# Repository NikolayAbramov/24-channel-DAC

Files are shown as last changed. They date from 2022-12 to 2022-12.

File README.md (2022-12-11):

# 24-channel DAC
This is hardware project of a 24-channel DAC with isolated output controlled via Ethernet interface. 

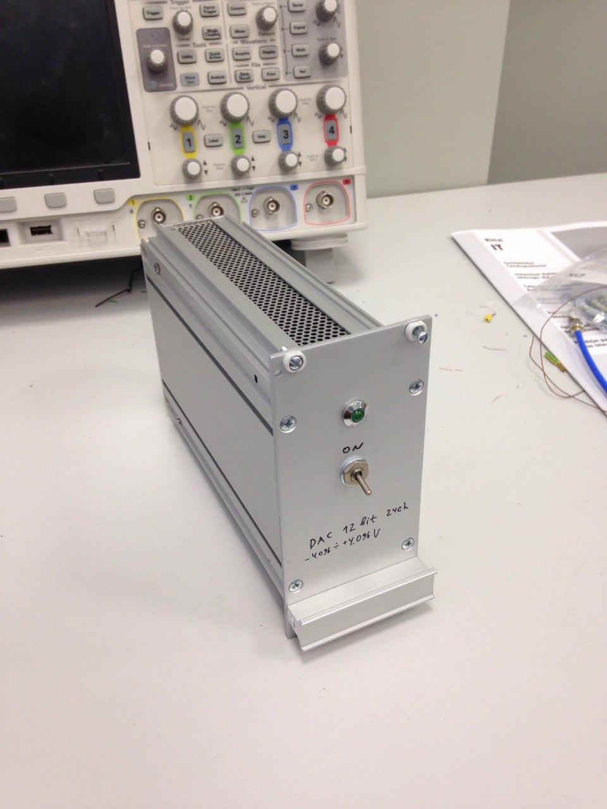
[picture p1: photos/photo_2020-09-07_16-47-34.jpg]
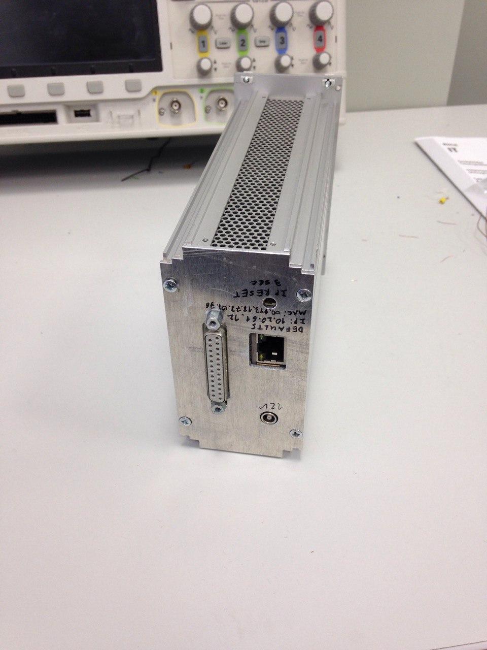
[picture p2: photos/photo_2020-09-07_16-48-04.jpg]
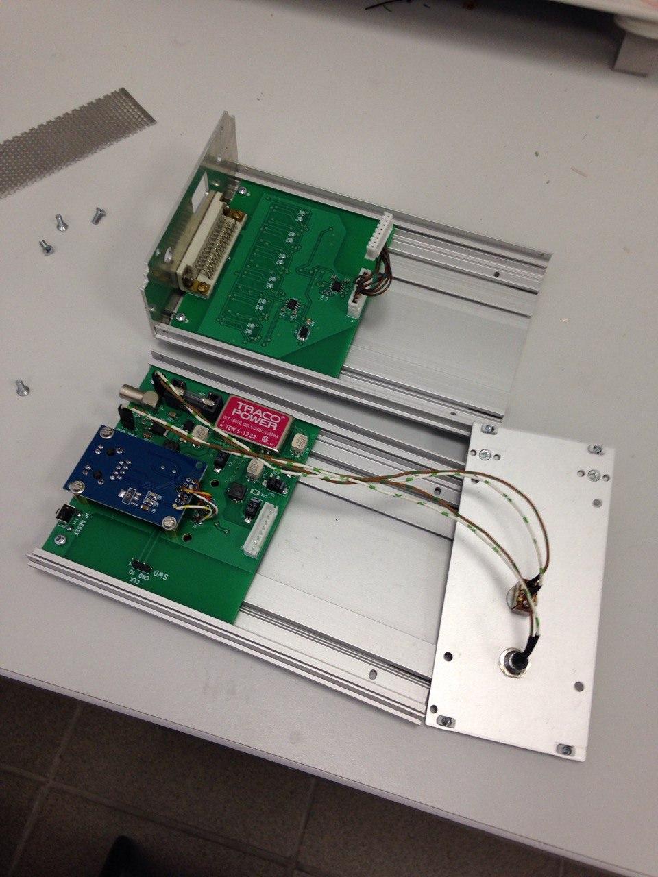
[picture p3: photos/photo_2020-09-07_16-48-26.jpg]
  

# Specs
- Number of outputs: 24
- Resolution: 10 bit
- Output voltage: from -4.096 V to +4.096 V
- Output current: 10 mA max
- Output configuration: 24 channels with common rail, isolated from power supply
- Control: Ethernet with web interface and SCPI commands
- Power: 12V

# Details
The schematics and PCB files can be found in the /kicad folder, they are created using KiCAD. The schematics are also presented in PDF. There are 2 boards: the controller bord and the DAC board. The controller board contains a STM32 MCU, an isolated power coverter and an Ethernet PHY module. An of-the-shelf ENC28J60 module is used for the Ethernet. The DAC board is connected via isolated I2C and contains four 8-channel DAC ICs, reference source and output buffers.

The firmware for STM32 MCU can be found in the /STM32_firmware folder. The project is for STM32CubeIDE.

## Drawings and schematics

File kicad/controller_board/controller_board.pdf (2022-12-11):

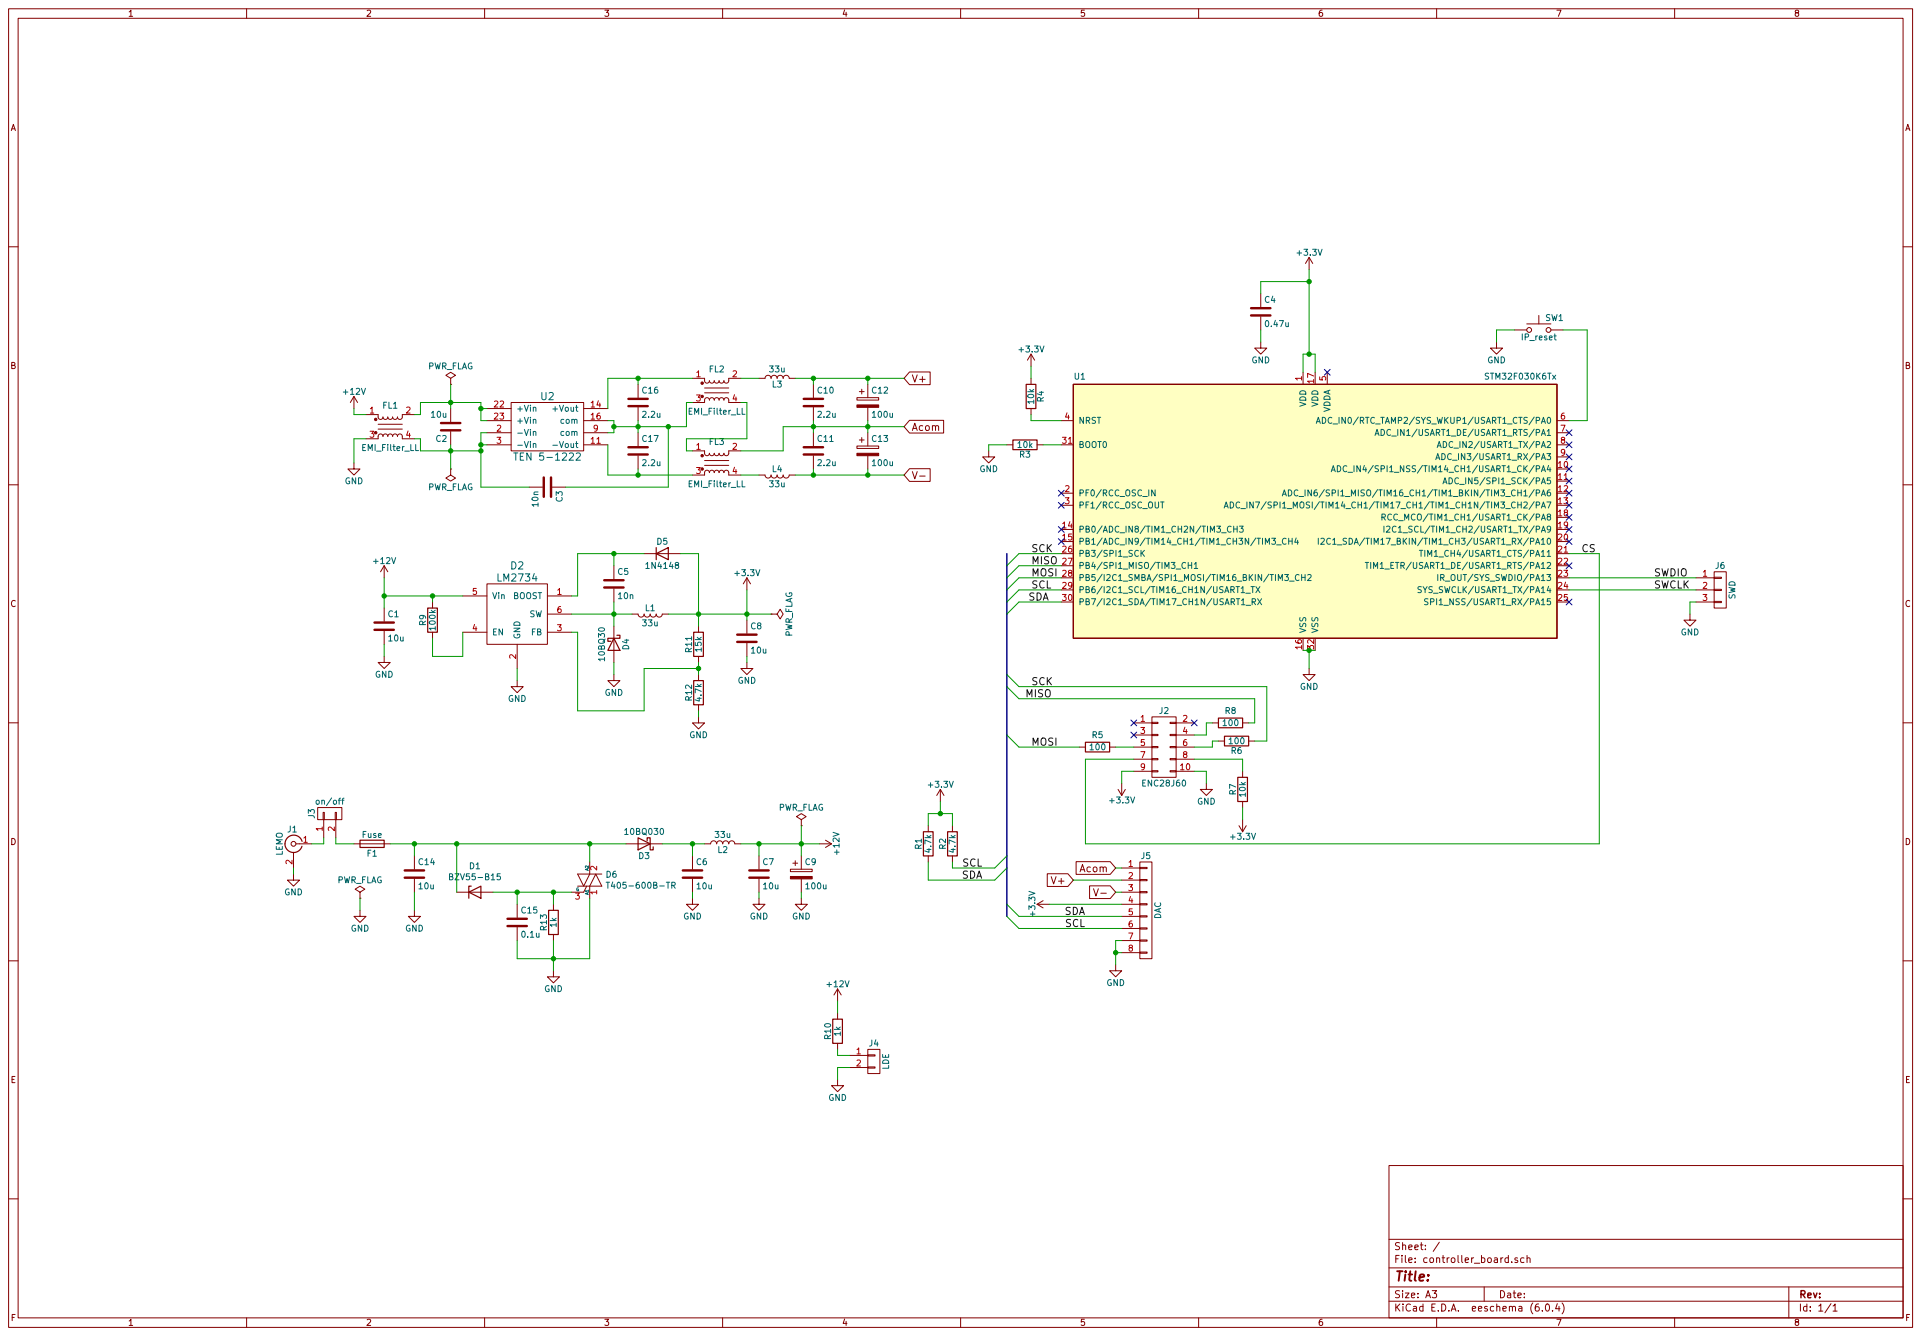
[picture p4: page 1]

2 FB 3 EN 4 Vin 5 SW 6 D2

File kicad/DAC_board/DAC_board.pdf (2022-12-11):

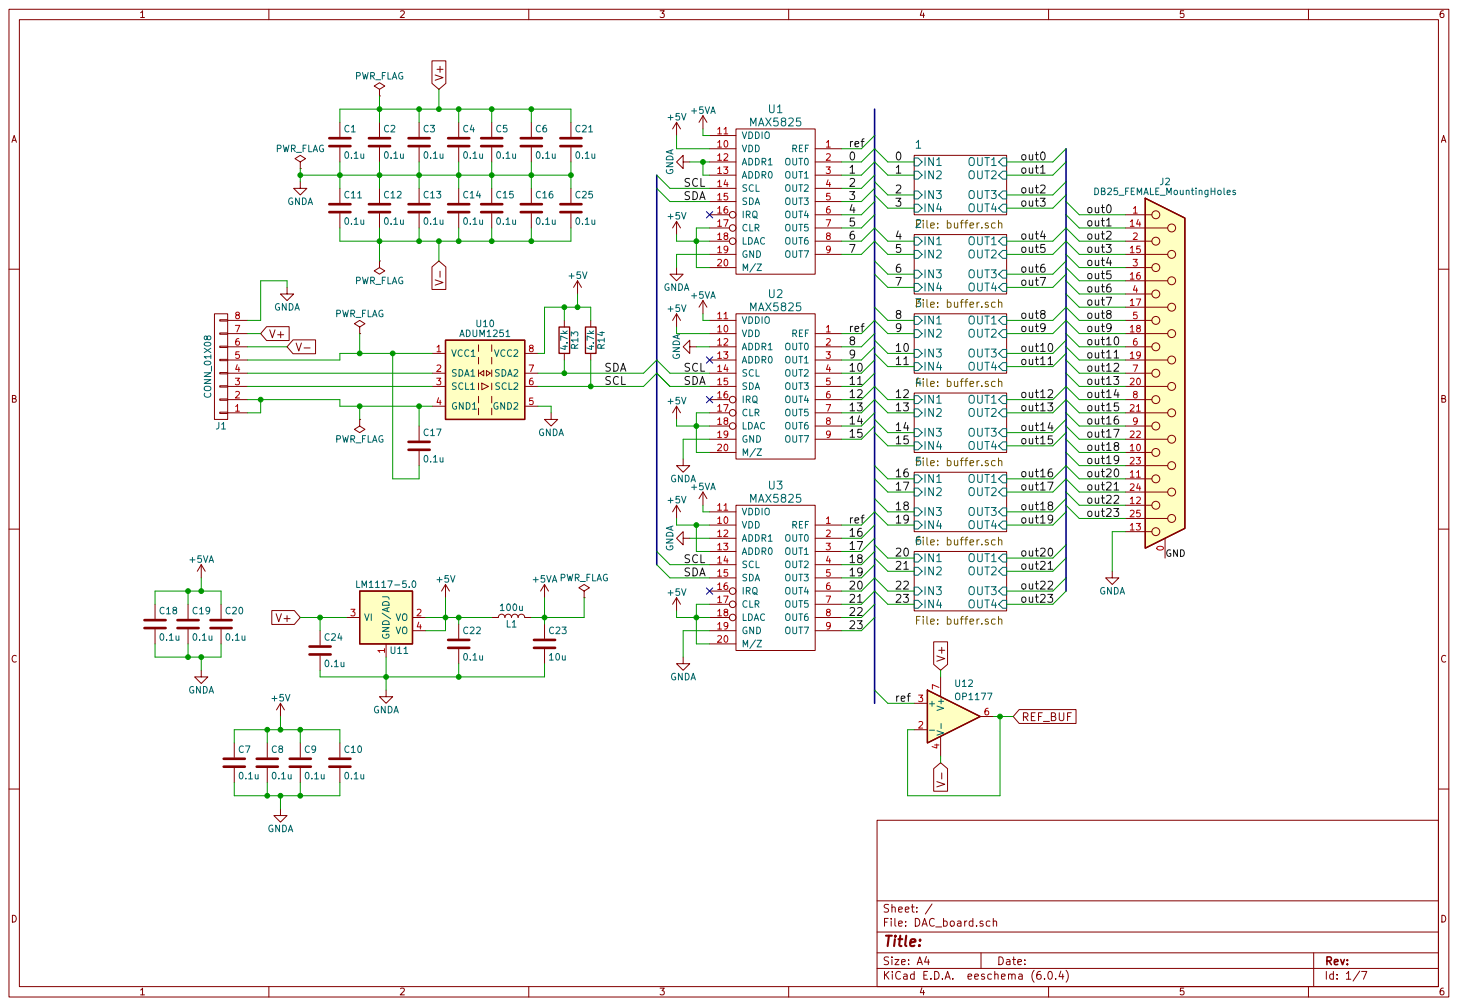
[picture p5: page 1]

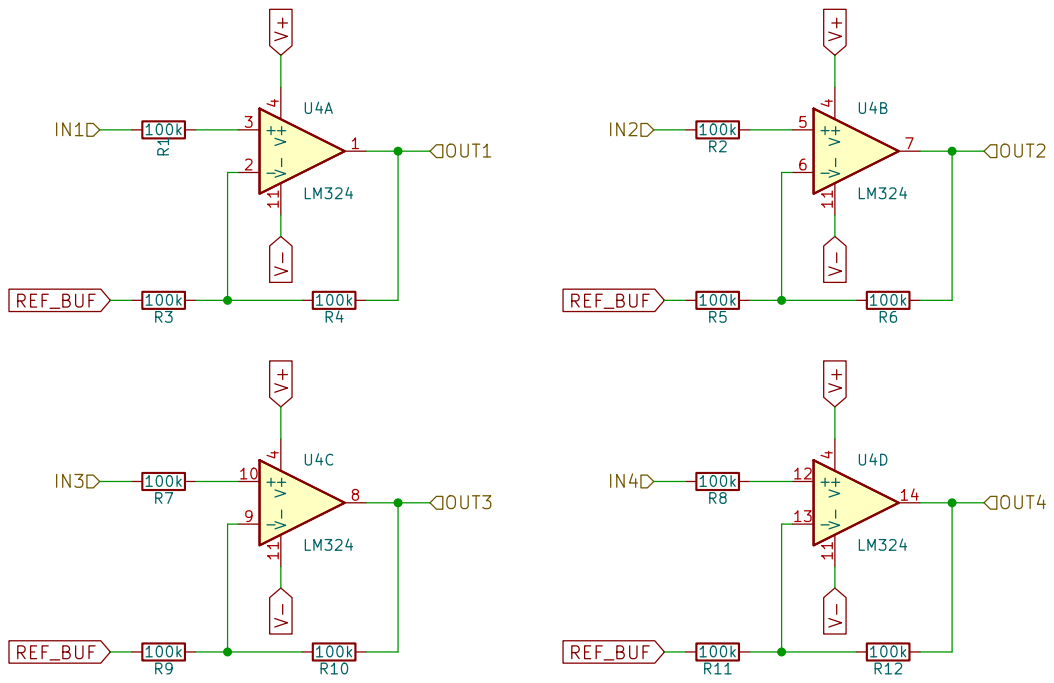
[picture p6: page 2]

Id: 2/7 Title: File: buffer.sch Sheet: /1/ R1

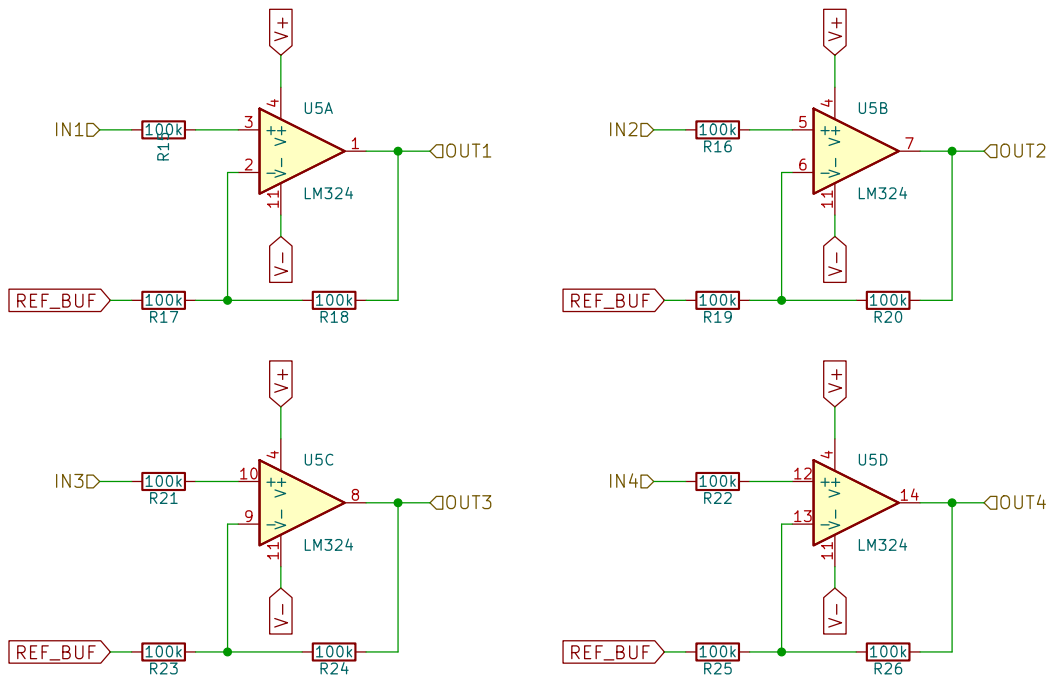
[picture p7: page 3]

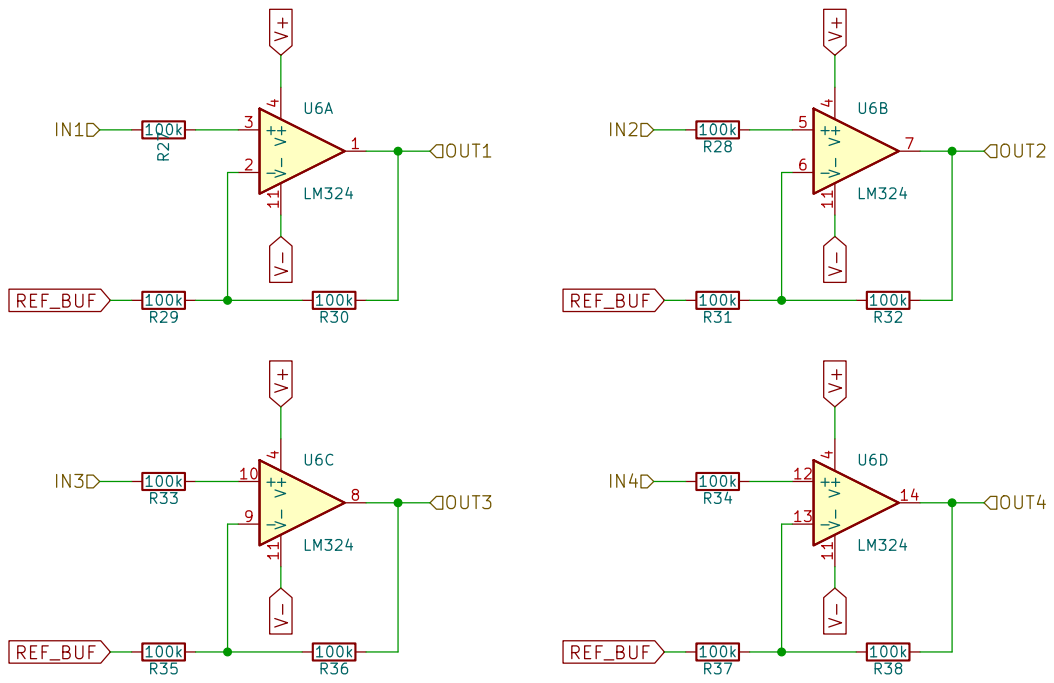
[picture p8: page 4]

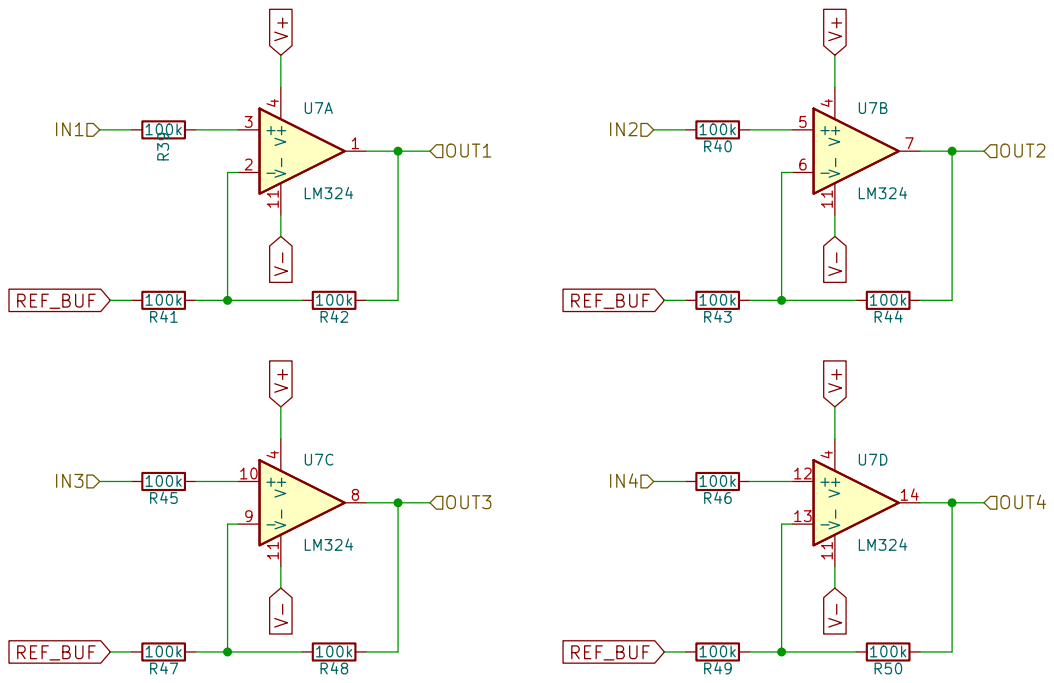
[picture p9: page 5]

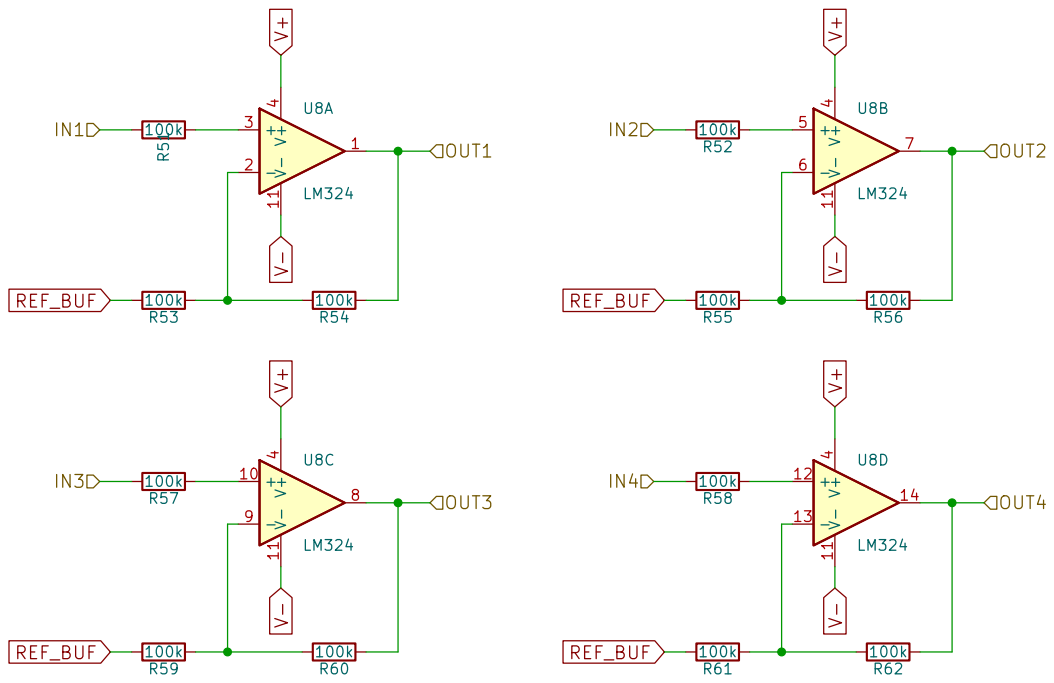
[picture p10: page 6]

Id: 6/7 Title: File: buffer.sch Sheet: /5/ R51

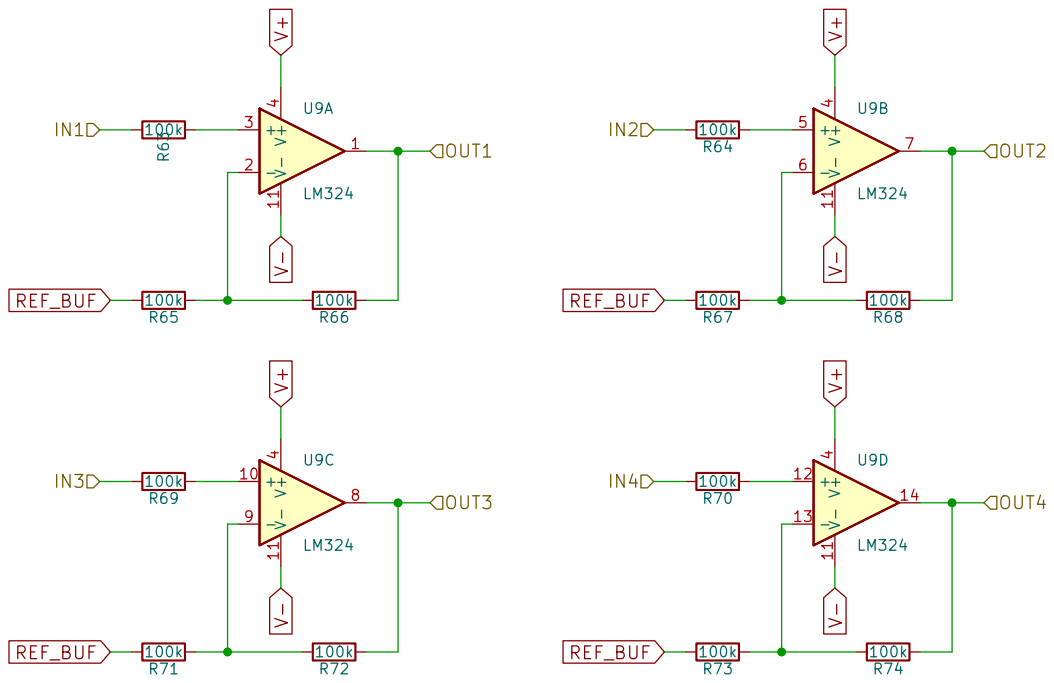
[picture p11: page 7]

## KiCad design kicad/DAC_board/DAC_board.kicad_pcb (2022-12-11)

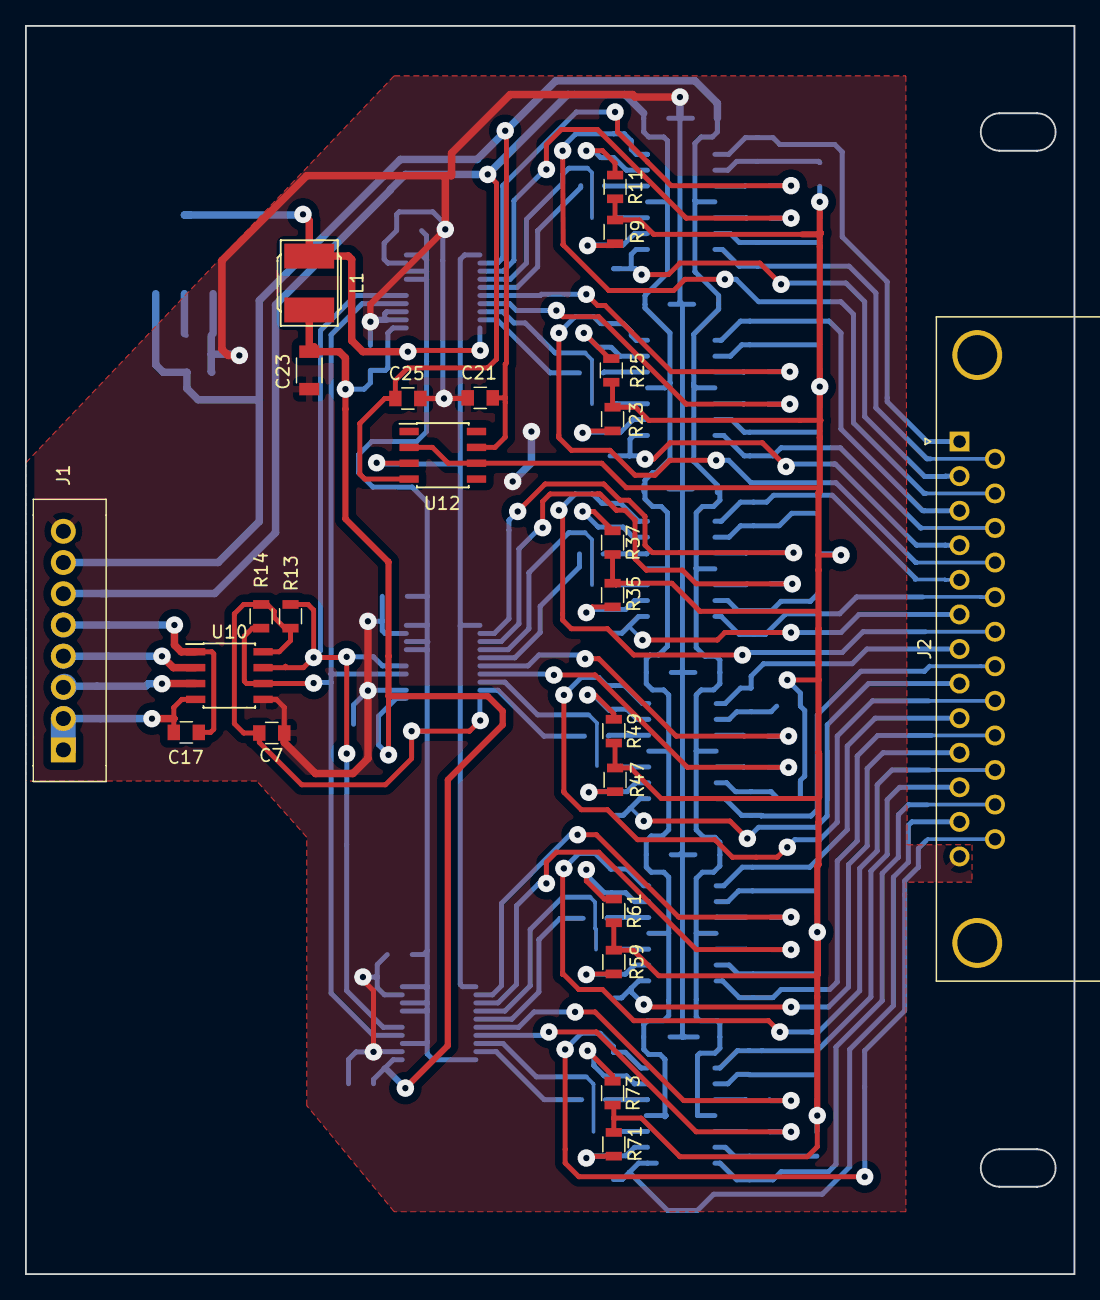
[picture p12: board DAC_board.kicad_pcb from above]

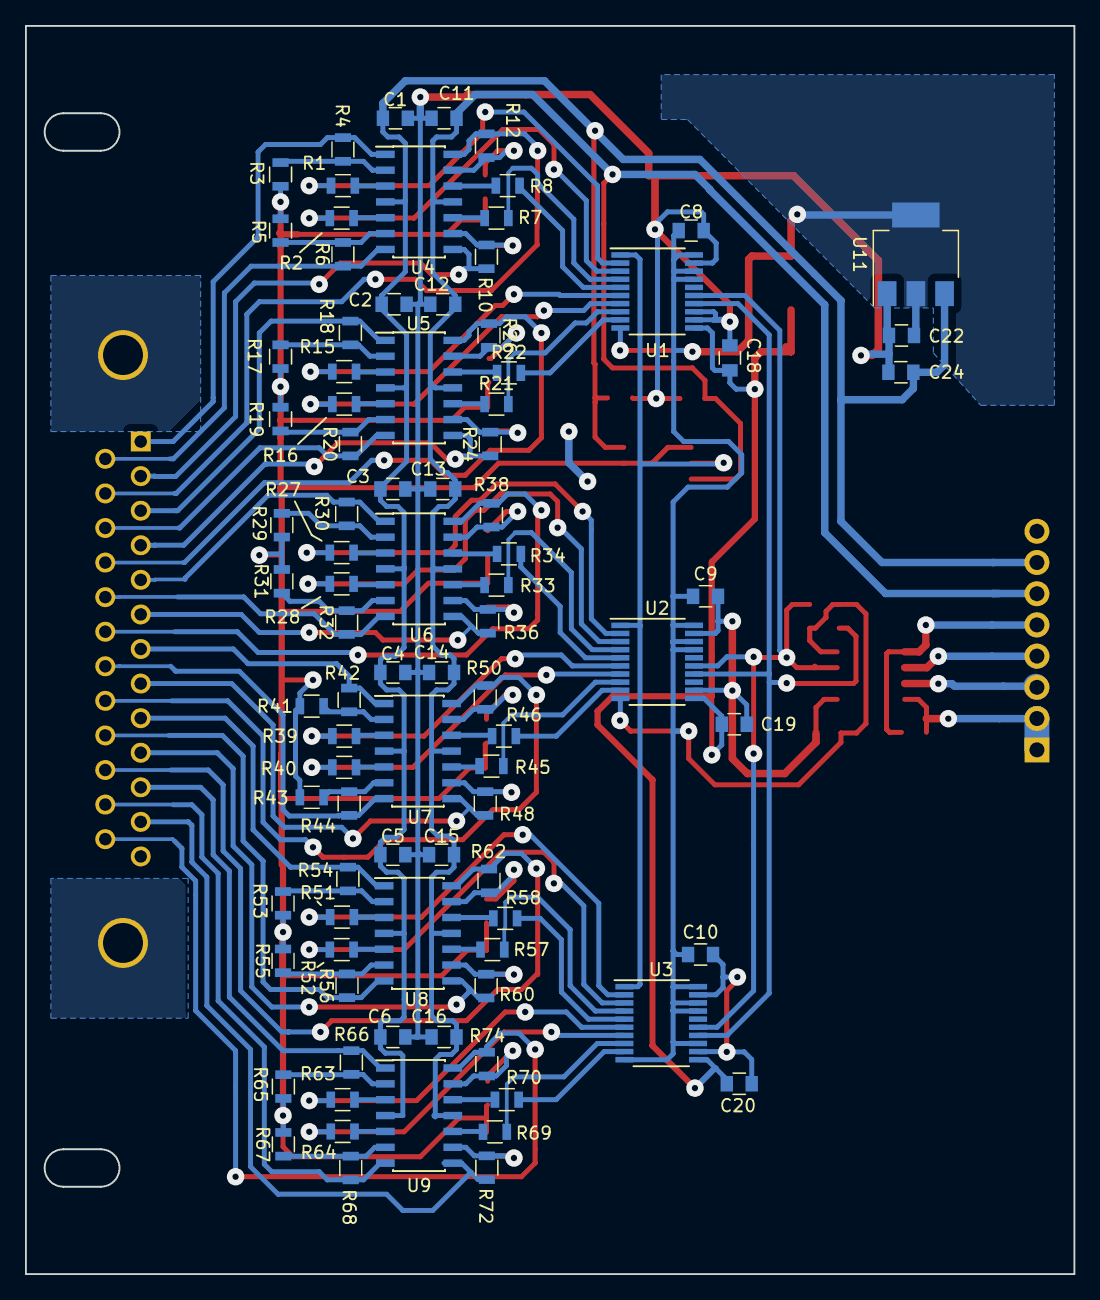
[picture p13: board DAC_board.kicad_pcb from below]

Board: 2 copper layers, 84.0 x 100.0 mm, 114 parts (90 on the bottom side), 109 nets.

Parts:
C1, C2, C3, C4, C5, C6, C7, C8, C9, C10, C11, C12, C13, C14, C15, C16, C17, C18, C19, C20, C21, C22, C24, C25: C; C_0805
C23: C; C_1206
J1: CONN_01X08; Wafer_Vertical22.5x5.8x7RM2.5-8
J2: DB25_FEMALE_MountingHoles; DSUB-25_Female_Horizontal_P2.77x2.84mm_EdgePinOffset9.90mm_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
L1: L; Choke_SMD_Taiyo_NRS50XX-Handsoldering
R1, R2, R3, R4, R5, R6, R7, R8, R9, R10, R11, R12, R13, R14, R15, R16, R17, R18, R19, R20, R21, R22, R23, R24, R25, R26, R27, R28, R29, R30, R31, R32, R33, R34, R35, R36, R37, R38, R39, R40, R41, R42, R43, R44, R45, R46, R47, R48, R49, R50, R51, R52, R53, R54, R55, R56, R57, R58, R59, R60, R61, R62, R63, R64, R65, R66, R67, R68, R69, R70, R71, R72, R73, R74: R; R_0805
U1, U2, U3: MAX5825; TSSOP-20_4.4x6.5mm_Pitch0.65mm
U4, U5, U6, U7, U8, U9: LM324; SOIC-14_3.9x8.7mm_Pitch1.27mm
U10: ADUM1251; SOIC-8_3.9x4.9mm_Pitch1.27mm
U11: LM1117-5.0; SOT-223
U12: OP1177; SOIC-8_3.9x4.9mm_Pitch1.27mm

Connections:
+5V: C7.1, C8.1, C9.1, C10.1, C22.1, L1.1, R13.1, R14.1, U1.10, U1.17, U1.18, U1.20, U2.10, U2.17, U2.18, U2.20, U3.10, U3.13, U3.17, U3.18, U3.20, U10.8, U11.2, U11.4
+5VA: C18.1, C19.1, C20.1, C23.1, L1.2, U1.11, U2.11, U3.11
/0: R1.2, U1.2
/1: R2.2, U1.3
/2: R7.2, U1.4
/3: R8.2, U1.5
/4: R15.2, U1.6
/5: R16.2, U1.7
/6: R21.2, U1.8
/7: R22.2, U1.9
/8: R27.2, U2.2
/9: R28.2, U2.3
/10: R33.2, U2.4
/11: R34.2, U2.5
/12: R39.2, U2.6
/13: R40.2, U2.7
/14: R45.2, U2.8
/15: R46.2, U2.9
/16: R51.2, U3.2
/17: R52.2, U3.3
/18: R57.2, U3.4
/19: R58.2, U3.5
/20: R63.2, U3.6
/21: R64.2, U3.7
/22: R69.2, U3.8
/23: R70.2, U3.9
/SCL: R14.2, U1.14, U2.14, U3.14, U10.6
/SDA: R13.2, U1.15, U2.15, U3.15, U10.7
/out0: J2.1, R4.1, U4.1
/out1: J2.14, R6.1, U4.7
/out2: J2.2, R10.1, U4.8
/out3: J2.15, R12.1, U4.14
/out4: J2.3, R18.1, U5.1
/out5: J2.16, R20.1, U5.7
/out6: J2.4, R24.1, U5.8
/out7: J2.17, R26.1, U5.14
/out8: J2.5, R30.1, U6.1
/out9: J2.18, R32.1, U6.7
/out10: J2.6, R36.1, U6.8
/out11: J2.19, R38.1, U6.14
/out12: J2.7, R42.1, U7.1
/out13: J2.20, R44.1, U7.7
/out14: J2.8, R48.1, U7.8
/out15: J2.21, R50.1, U7.14
/out16: J2.9, R54.1, U8.1
/out17: J2.22, R56.1, U8.7
/out18: J2.10, R60.1, U8.8
/out19: J2.23, R62.1, U8.14
/out20: J2.11, R66.1, U9.1
/out21: J2.24, R68.1, U9.7
/out22: J2.12, R72.1, U9.8
/out23: J2.25, R74.1, U9.14
/ref: U1.1, U2.1, U3.1, U12.3
GNDA: C1.2, C2.2, C3.2, C4.2, C5.2, C6.2, C7.2, C8.2, C9.2, C10.2, C11.1, C12.1, C13.1, C14.1, C15.1, C16.1, C18.2, C19.2, C20.2, C21.2, C22.2, C23.2, C24.2, C25.1, J1.8, J2.13, U1.12, U1.13, U1.19, U2.12, U2.19, U3.12, U3.19, U10.5, U11.1
unnamed: C17.1, J1.1, J1.2, U10.4
unnamed: C17.2, J1.5, U10.1
unnamed: J1.3, U10.3
unnamed: J1.4, U10.2
unnamed: R1.1, U4.3
unnamed: R2.1, U4.5
unnamed: R3.1, R4.2, U4.2
unnamed: R5.1, R6.2, U4.6
unnamed: R7.1, U4.10
unnamed: R8.1, U4.12
unnamed: R9.1, R10.2, U4.9
unnamed: R11.1, R12.2, U4.13
unnamed: R15.1, U5.3
unnamed: R16.1, U5.5
unnamed: R17.1, R18.2, U5.2
unnamed: R19.1, R20.2, U5.6
unnamed: R21.1, U5.10
unnamed: R22.1, U5.12
unnamed: R23.1, R24.2, U5.9
unnamed: R25.1, R26.2, U5.13
unnamed: R27.1, U6.3
unnamed: R28.1, U6.5
unnamed: R29.1, R30.2, U6.2
unnamed: R31.1, R32.2, U6.6
unnamed: R33.1, U6.10
unnamed: R34.1, U6.12
unnamed: R35.1, R36.2, U6.9
unnamed: R37.1, R38.2, U6.13
unnamed: R39.1, U7.3
unnamed: R40.1, U7.5
unnamed: R41.1, R42.2, U7.2
unnamed: R43.1, R44.2, U7.6
unnamed: R45.1, U7.10
unnamed: R46.1, U7.12
unnamed: R47.1, R48.2, U7.9
unnamed: R49.1, R50.2, U7.13
unnamed: R51.1, U8.3
unnamed: R52.1, U8.5
unnamed: R53.1, R54.2, U8.2
unnamed: R55.1, R56.2, U8.6
unnamed: R57.1, U8.10
unnamed: R58.1, U8.12
unnamed: R59.1, R60.2, U8.9
unnamed: R61.1, R62.2, U8.13
unnamed: R63.1, U9.3
unnamed: R64.1, U9.5
unnamed: R65.1, R66.2, U9.2
unnamed: R67.1, R68.2, U9.6
unnamed: R69.1, U9.10
unnamed: R70.1, U9.12
unnamed: R71.1, R72.2, U9.9
unnamed: R73.1, R74.2, U9.13
REF_BUF: R3.2, R5.2, R9.2, R11.2, R17.2, R19.2, R23.2, R25.2, R29.2, R31.2, R35.2, R37.2, R41.2, R43.2, R47.2, R49.2, R53.2, R55.2, R59.2, R61.2, R65.2, R67.2, R71.2, R73.2, U12.2, U12.6
V+: C1.1, C2.1, C3.1, C4.1, C5.1, C6.1, C21.1, C24.1, J1.7, U4.4, U5.4, U6.4, U7.4, U8.4, U9.4, U11.3, U12.7
V-: C11.2, C12.2, C13.2, C14.2, C15.2, C16.2, C25.2, J1.6, U4.11, U5.11, U6.11, U7.11, U8.11, U9.11, U12.4

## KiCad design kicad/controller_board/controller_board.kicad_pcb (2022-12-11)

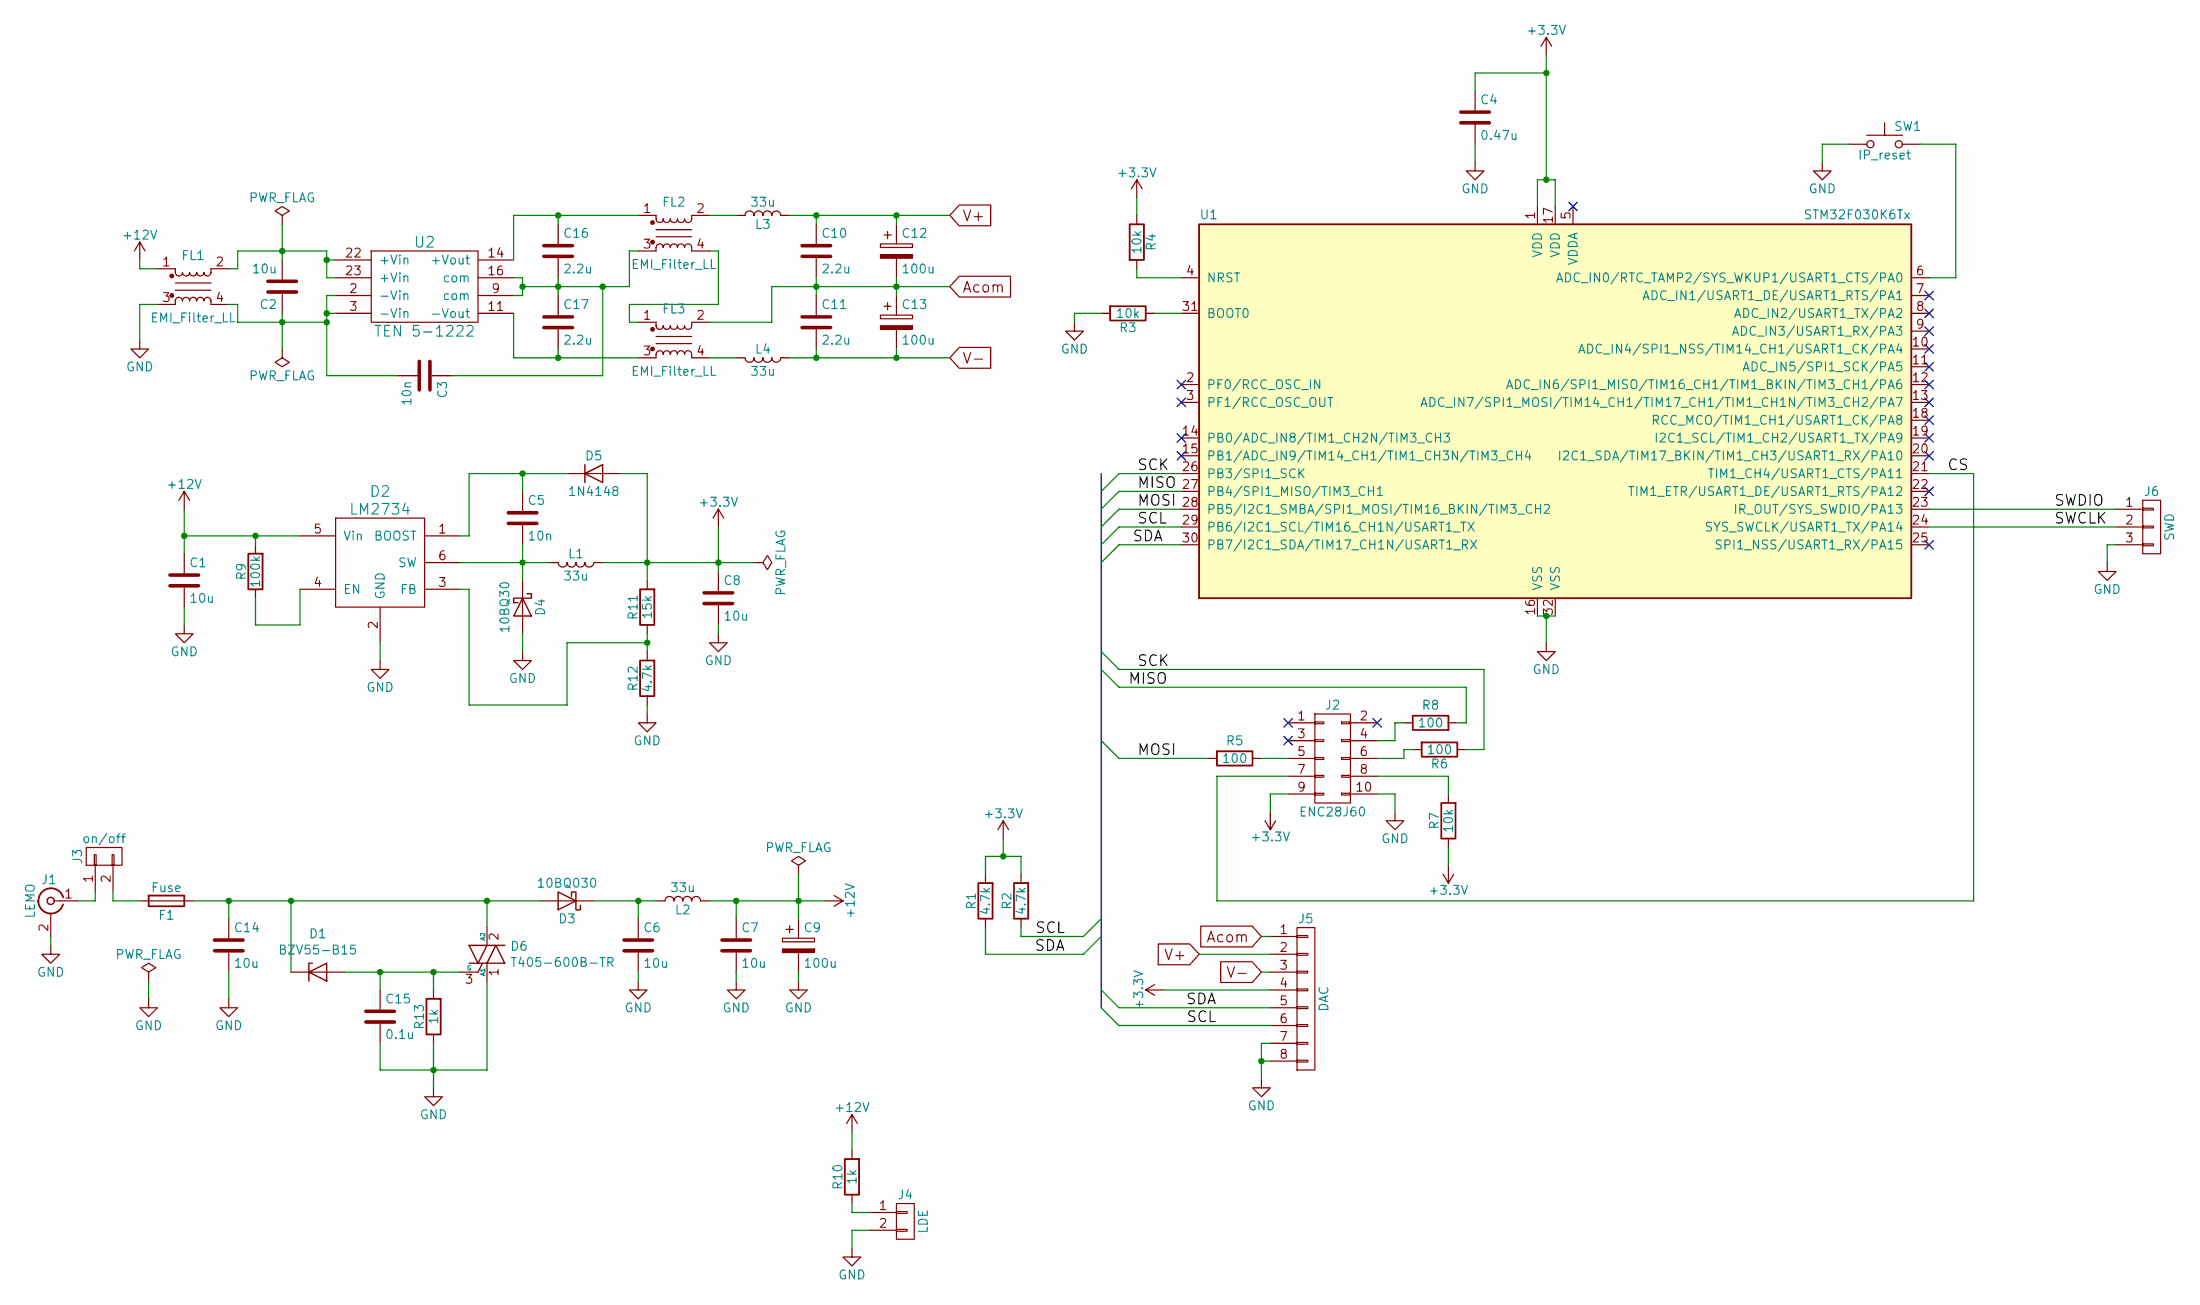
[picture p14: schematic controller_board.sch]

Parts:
C1, C2, C6, C7, C8: 10u; C_1206
C3, C5: 10n; C_1206
C4: 0.47u; C_0805
C9, C12, C13: 100u; CP_Tantalum_Case-D_EIA-7343-31_Hand
C10, C11, C16, C17: 2.2u; C_1206
C14: 10u; C_1210
C15: 0.1u; C_0805
D1: BZV55-B15; D_1206
D2: LM2734; SuperSOT-6
D3: 10BQ030; D_SMB
D4: 10BQ30; D_SMB
D5: 1N4148; D_SOD-123
D6: T405-600B-TR; TO-252-2
F1: Fuse; FH-101
FL1, FL2, FL3: EMI_Filter_LL; Bourns_B82790
J1: LEMO; LEMO_00_R
J2: ENC28J60; ENC28J60_module
J3: on/off; Pin_Header_Straight_1x02_Pitch2.54mm
J4: LDE; Pin_Header_Straight_1x02_Pitch2.54mm
J5: DAC; Wafer_Vertical22.5x5.8x7RM2.5-8
J6: SWD; Pin_Header_Straight_1x03_Pitch2.54mm
L1, L2, L3, L4: 33u; SRR0603
R1, R2, R12: 4.7k; R_0805
R3, R4, R7: 10k; R_0805
R5, R6, R8: 100; R_0805
R9: 100k; R_0805
R10, R13: 1k; R_0805
R11: 15k; R_0805
SW1: IP_reset; SW_Tactile_SPST_Angled_PTS645Vx39-2LFS
U1: STM32F030K6Tx; QFP_32
U2: TEN 5-1222; Traco_TEN5

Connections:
+3V3: C4.1, C8.1, D5.2 (A), J2.9, J5.4, L1.1, R1.2, R2.2, R4.1, R7.1, R11.2, U1.1 (VDD), U1.17 (VDD)
+12V: C1.1, C7.1, C9.1, D2.5 (Vin), FL1.1, L2.2, R9.2, R10.2
/CS: J2.7, U1.21 (TIM1_CH4/USART1_CTS/PA11)
/MISO: R8.2, U1.27 (PB4/SPI1_MISO/TIM3_CH1)
/MOSI: R5.2, U1.28 (PB5/I2C1_SMBA/SPI1_MOSI/TIM16_BKIN/TIM3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)
/SCK: R6.1, U1.26 (PB3/SPI1_SCK)
/SCL: J5.6, R2.1, U1.29 (PB6/I2C1_SCL/TIM16_CH1N/USART1_TX)
/SDA: J5.5, R1.1, U1.30 (PB7/I2C1_SDA/TIM17_CH1N/USART1_RX)
/SWCLK: J6.2, U1.24 (SYS_SWCLK/USART1_TX/PA14)
/SWDIO: J6.1, U1.23 (IR_OUT/SYS_SWDIO/PA13)
Acom: C10.2, C11.1, C12.2, C13.1, FL3.2, J5.1
GND: C1.2, C4.2, C6.2, C7.2, C8.2, C9.2, C14.2, C15.2, D2.2 (GND), D4.2 (A), D6.1 (A1), FL1.3, J1.2 (Ext), J2.10, J4.2, J5.7, J5.8, J6.3, R3.2, R12.1, R13.1, SW1.1, U1.16 (VSS), U1.32 (VSS)
unnamed: C2.1, C3.2, FL1.4, U2.2 (-Vin), U2.3 (-Vin)
unnamed: C2.2, FL1.2, U2.22 (+Vin), U2.23 (+Vin)
unnamed: C5.1, D2.1 (BOOST), D5.1 (K)
unnamed: C5.2, D2.6 (SW), D4.1 (K), L1.2
unnamed: C6.1, D3.1 (K), L2.1
unnamed: C14.1, D1.1 (K), D3.2 (A), D6.2 (A2), F1.1
unnamed: C15.1, D1.2 (A), D6.3 (G), R13.2
unnamed: C16.1, FL2.1, U2.14 (+Vout)
unnamed: C3.1, C16.2, C17.1, FL2.3, U2.9 (com), U2.16 (com)
unnamed: C17.2, FL3.3, U2.11 (-Vout)
unnamed: D2.3 (FB), R11.1, R12.2
unnamed: D2.4 (EN), R9.1
unnamed: F1.2, J3.2
unnamed: FL2.2, L3.1
unnamed: FL2.4, FL3.1
unnamed: FL3.4, L4.2
unnamed: J1.1 (In), J3.1
unnamed: J2.4, R8.1
unnamed: J2.5, R5.1
unnamed: J2.6, R6.2
unnamed: J2.8, R7.2
unnamed: J4.1, R10.1
unnamed: R3.1, U1.31 (BOOT0)
unnamed: R4.2, U1.4 (NRST)
unnamed: SW1.2, U1.6 (ADC_IN0/RTC_TAMP2/SYS_WKUP1/USART1_CTS/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)
V+: C10.1, C12.1, J5.2, L3.2
V-: C11.2, C13.2, J5.3, L4.1

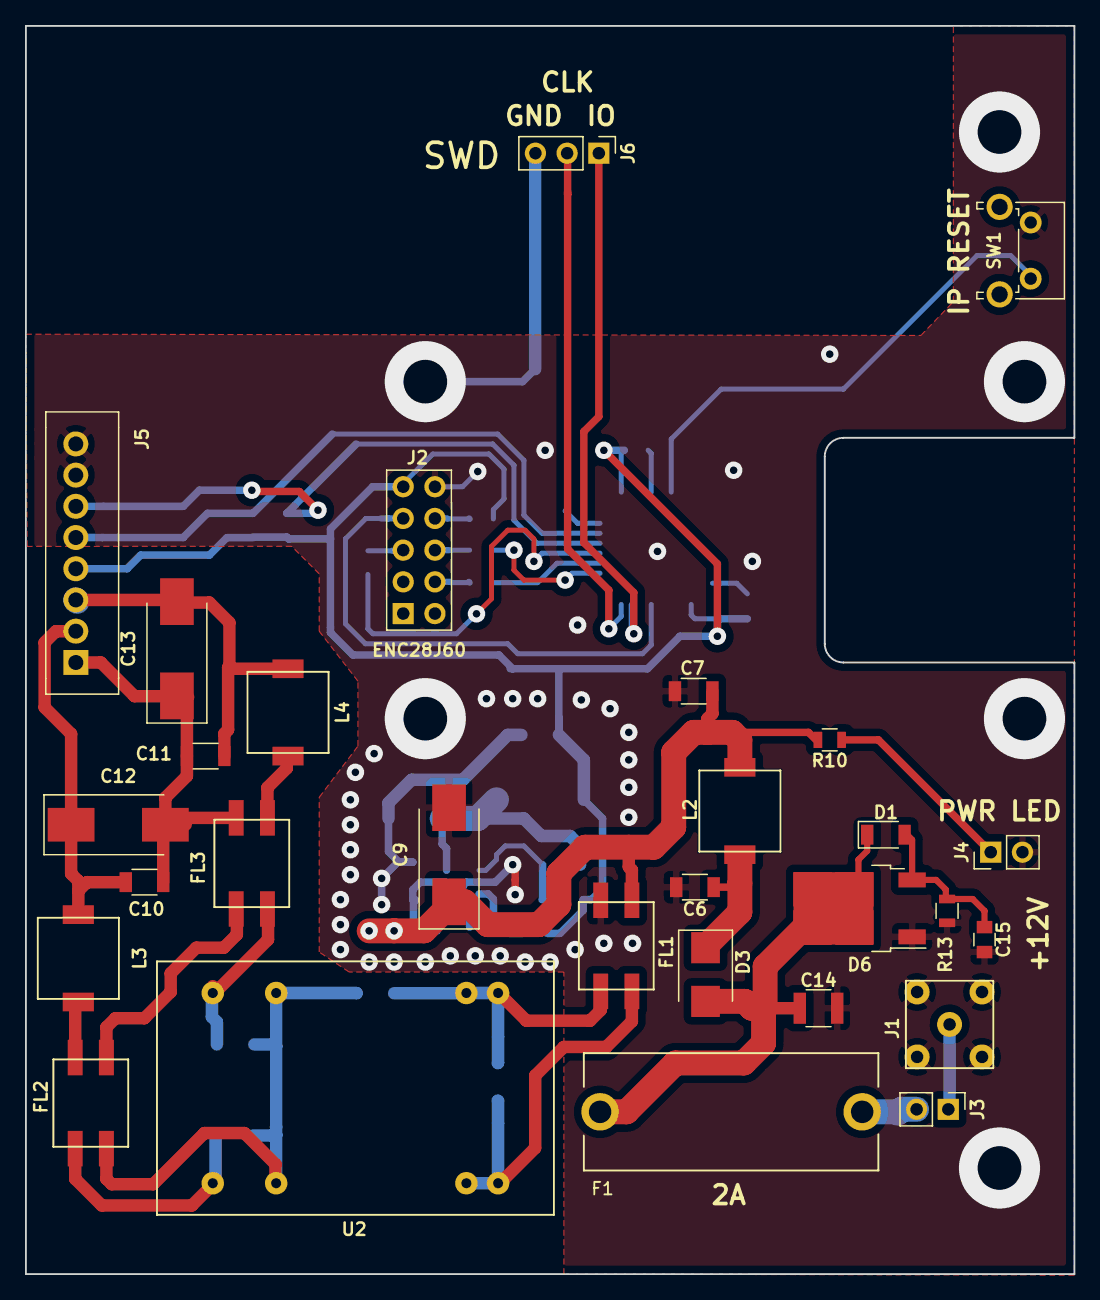
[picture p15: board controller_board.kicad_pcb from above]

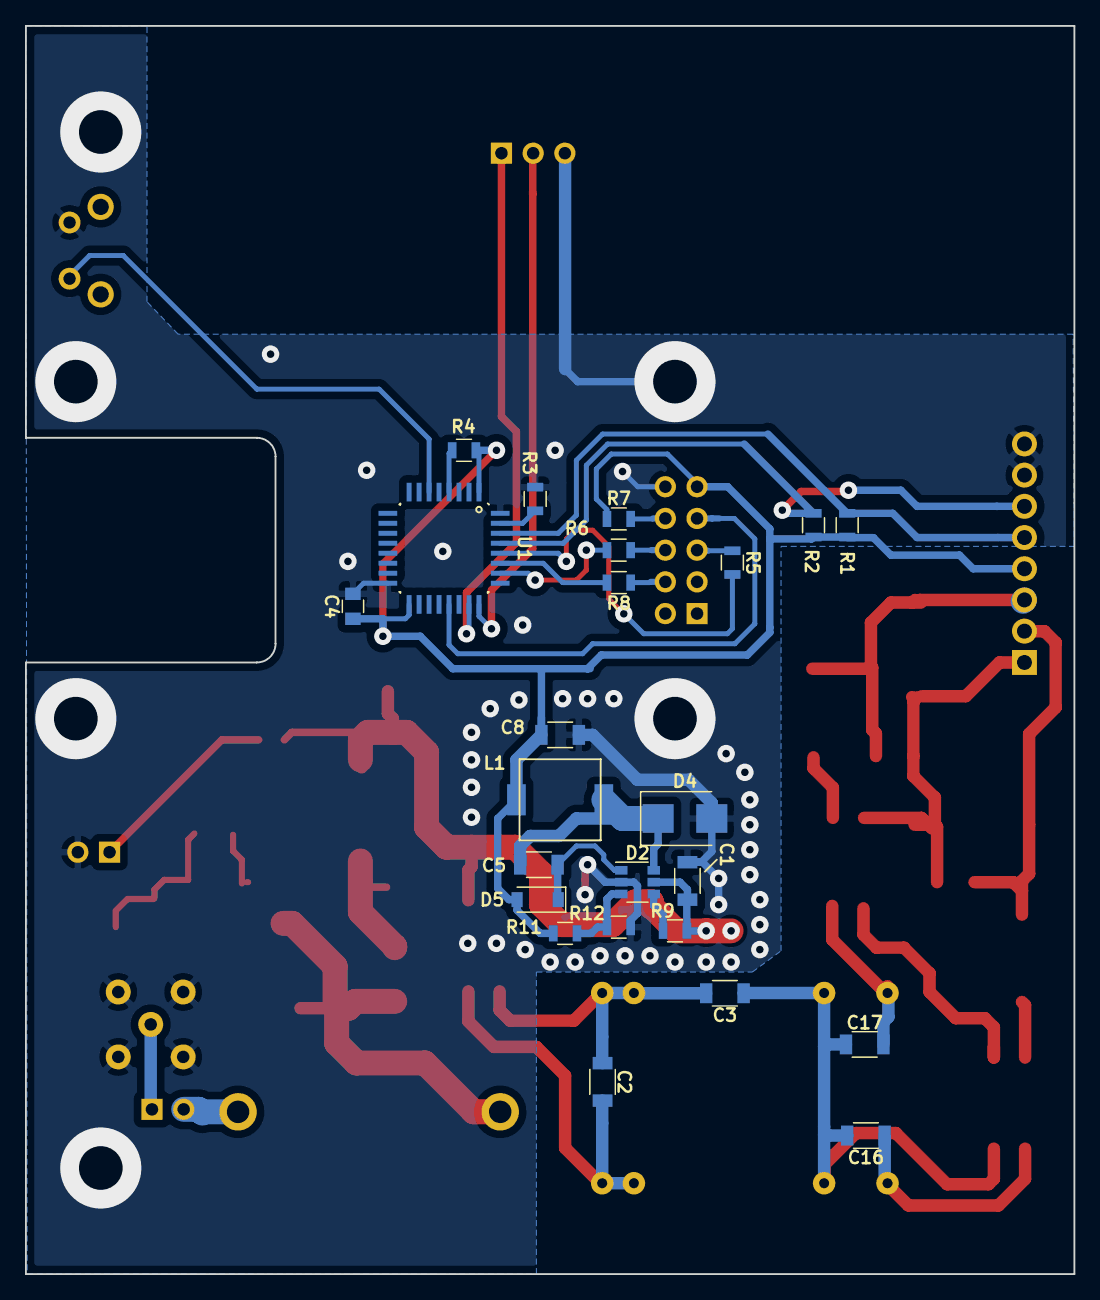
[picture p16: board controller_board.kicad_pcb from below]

Board: 2 copper layers, 84.0 x 100.0 mm, 53 parts (24 on the bottom side), 39 nets.

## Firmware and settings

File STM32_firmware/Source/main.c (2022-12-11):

#include <string.h>

#include "stm32f0xx.h"
#include "hardware_init.h"
#include "I2C.h"
#include "enc28j60.h"
#include "MAX582x/MAX582x.h"
#include "timer.h"

#include "uip.h"
#include "uip_arp.h"
#include "uiplib.h"

#include "MDAC_conf.h"
#include "MAX582x/dac_functions.h"
#include "flash/flash.h"
#include "crc/crc.h"
#include "net_interface.h"

//TCP/IP buffer
#define BUF ( (struct uip_eth_hdr *) uip_buf )

//I2C slave addresses of ICs
uint8_t DAC_addr[DAC_N] = {0,2,3};
//DATA buffer
uint16_t DAC_buffer[NCHAN]; 
////////////////////////////////////////////////////////////////
uint8_t global_flags = 0;

uint8_t pkt_cnt = 0;
uint8_t eri_val = 0, econ1, erxfcon;
uint16_t erxrdpt, erxwrpt;

int main(void){
	
	uint8_t i;
	//timers
	struct timer periodic_timer;
	struct timer arp_timer;
	struct timer led_timer;
	struct timer ip_reset_button_timer;
	struct timer ENC20J60_periodic_reset_timer;
	
	hardware_init();
	i2c_init();
	//Analog circuit powerup delay
	delay_long(200);
	
	max582_set_addr(DAC_addr[0]);
	if(!max582x_init_ref()){
			global_flags |= DAC_FAULT;
	}
	
	for(i=1; i<DAC_N; i++)
	{
		max582_set_addr(DAC_addr[i]);
		if(!max582x_init())
			global_flags |= DAC_FAULT;
	}
	
	if( !dac_read_all() ){
		global_flags |= DAC_ERROR;
	}

	// TCP/IP
	uip_init();
	uip_arp_init();
	load_net_addr();
	
	enc28j60PhyWrite(PHLCON,0x476);
	
	net_interface_init();
	
	//ms timers
	timer_set( &periodic_timer, 1000);
	timer_set( &arp_timer, 10000);
	timer_set( &led_timer, 500);
	timer_set( &ENC20J60_periodic_reset_timer, 300000);
	
	while(1){
		/*
		//LED blinking
		//delay(80000);
		if(timer_expired(&led_timer)){
			//GPIOA->ODR &= ~GPIO_ODR_3;
			if (GPIOA->ODR & GPIO_ODR_3 ){
			GPIOA->ODR &= ~GPIO_ODR_3;
		}else{
			GPIOA->ODR |= GPIO_ODR_3;
		}
			timer_restart(&led_timer);
		}*/
		//Buttons
		if(!IP_RESET_BUTTON){
			if (!ip_reset_button_timer.run){
				timer_set(&ip_reset_button_timer, 3000);
			}
		}
		else if(ip_reset_button_timer.run){
				ip_reset_button_timer.run = 0;
		}
		if( timer_expired(&ip_reset_button_timer) && !IP_RESET_BUTTON){
			//Change IP/MAC to default
			set_default_net_addr();
			save_net_addr();
		}
		/*
		pkt_cnt = enc28j60Read(EPKTCNT);
		eri_val = enc28j60Read(EIR);
		erxrdpt = ((uint16_t)enc28j60Read(ERXRDPTH))<<8 | (uint16_t)enc28j60Read(ERXRDPTL);
		erxwrpt = ((uint16_t)enc28j60Read(ERXWRPTH))<<8 | (uint16_t)enc28j60Read(ERXWRPTL);
		econ1 = enc28j60Read(ECON1);
		erxfcon = enc28j60Read(ERXFCON);*/
		
		//TCP/IP
		//Periodically reset ENC28J60 if there are no opened connections
		//Just in case
		if( get_num_of_conns(UIP_CLOSED) == UIP_CONNS){
				if( timer_expired( &ENC20J60_periodic_reset_timer)){
					enc28j60Init();
					timer_restart( &ENC20J60_periodic_reset_timer);
				}
		}else{
				timer_restart( &ENC20J60_periodic_reset_timer);
		}
	
		uip_len = enc28j60PacketReceive(UIP_BUFSIZE, uip_buf);
		
		if (uip_len >0){
			if(BUF->type == htons(UIP_ETHTYPE_ARP)){
					uip_arp_arpin();
					if(uip_len > 0){
						uip_len = 0x3C;
						enc28j60PacketSend(uip_len, uip_buf );
					}
      }else if(BUF->type == htons(UIP_ETHTYPE_IP)){
				uip_arp_ipin();
				uip_input();
				if(uip_len > 0){
					uip_arp_out();
					enc28j60PacketSend(uip_len, uip_buf );
				}
			}
		//Periodic TCP/IP stuff
		}else if(timer_expired(&periodic_timer)){
				timer_restart(&periodic_timer);
				for(i = 0; i < UIP_CONNS; i++){
					uip_periodic(i);
					if(uip_len > 0){
						uip_arp_out();
						enc28j60PacketSend(uip_len, uip_buf );
					}
				}
		}else if(timer_expired(&arp_timer)){
				timer_restart(&arp_timer);
				uip_arp_timer();
		}
		//Change network addres
		if(global_flags & CHANGE_IP){
			uip_sethostaddr(my_net_addr.ip);
			global_flags &= ~CHANGE_IP;
		}
		if(global_flags & CHANGE_MAC){
			uip_setethaddr(my_net_addr.mac);
			enc28J60WriteMAC(my_net_addr.mac);
			global_flags &= ~CHANGE_MAC;
		}
	}
}

void TIM14_IRQHandler(){
	/*
	if (GPIOA->ODR & GPIO_ODR_3 ){
			GPIOA->ODR &= ~GPIO_ODR_3;
		}else{
			GPIOA->ODR |= GPIO_ODR_3;
		}*/
	//Clear flag
	TIM14->SR &= ~TIM_SR_UIF;
}

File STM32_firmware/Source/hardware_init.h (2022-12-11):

//ENC28J60 Wiring
#define ENC28J60_PORT_SPI   GPIOB
#define ENC28J60_PORT_CS   GPIOA
#define ENC28J60_CS 11
#define ENC28J60_SO 4
#define ENC28J60_SI 5
#define ENC28J60_SCK 3

//set CS to 0 = active
#define ENC28J60_CS_ACTIVE ENC28J60_PORT_CS->BSRR|=1<<(ENC28J60_CS+16)
//set CS to 1 = passive
#define ENC28J60_CS_PASSIVE ENC28J60_PORT_CS->BSRR|=1<<ENC28J60_CS

//IP & MAC reset button
#define IP_RESET_BUTTON (GPIOA->IDR & (uint32_t)0x1)

void hardware_init(void);

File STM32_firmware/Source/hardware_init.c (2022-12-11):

#include "stm32f0xx.h"
#include "timer.h"
#include "hardware_init.h"

void hardware_init()
{
	//Enable clock for ports A and B
	RCC->AHBENR |= RCC_AHBENR_GPIOAEN;
	RCC->AHBENR |= RCC_AHBENR_GPIOBEN;
	//-------------------------------------------------------------------------------------------------
	//Output
	GPIOA->MODER |= GPIO_MODER_MODER3_0;
	GPIOA->MODER &= ~GPIO_MODER_MODER3_1;
	//IP reset button pullup
	GPIOA->PUPDR |= GPIO_PUPDR_PUPDR0_0;
	GPIOA->PUPDR &= ~GPIO_PUPDR_PUPDR0_1;
	
	//Push-pull
	GPIOA->OTYPER &= ~GPIO_OTYPER_OT_3;
	//Low speed
	GPIOA->OSPEEDR &= ~GPIO_OSPEEDR_OSPEEDR3_0;
	//Enable clock for TIM14
	RCC->APB1ENR |= RCC_APB1ENR_TIM14EN;
	
	//ENC28J60 SPI
	//Alternative func mode for SPI pins SCK and MOSI and MISO
	ENC28J60_PORT_SPI->MODER |= ( 1<<(ENC28J60_SO*2+1) | 1<<(ENC28J60_SI*2+1) | 1<<(ENC28J60_SCK*2+1) );
	ENC28J60_PORT_SPI->MODER &= ~( 1<<ENC28J60_SO*2 | 1<<ENC28J60_SI*2 | 1<<ENC28J60_SCK*2 );
	//CS pin
	ENC28J60_PORT_CS->MODER |= ( 1<<ENC28J60_CS*2 );
	ENC28J60_PORT_CS->MODER &= ~( 1<<(ENC28J60_CS*2+1) );
	//MISO input with pullup
	//ENC28J60_PORT->PUPDR |= 1<<(ENC28J60_SO*2);
	//ENC28J60_PORT->PUPDR &= ~ ( 1<<(ENC28J60_SO*2+1) );
	//Push pull mode for SPI pins SCK , MOSI and CS
	ENC28J60_PORT_SPI->OTYPER &= ~( 1<<ENC28J60_SI | 1<<ENC28J60_SCK);
	ENC28J60_PORT_CS->OTYPER &= ~(1<<ENC28J60_CS);
	
	//CRC
	RCC->AHBENR |= RCC_AHBENR_CRCEN;
	
	//Timer
	TIM14->PSC = 8000;
	TIM14->ARR = 1000;
	TIM14->DIER |= TIM_DIER_UIE;
	//-------------------------------------------------------------------------------------------------
	//Run SysTick
	SysTick_Config( SYSTICK_RVR_VAL );
	//SysTick->CTRL &= ~SysTick_CTRL_TICKINT_Msk;
	
	//-------------------------------------------------------------------------------------------------
	//Interrupts
	NVIC_EnableIRQ(TIM14_IRQn);
	NVIC_EnableIRQ(SysTick_IRQn);
	TIM14->CR1 |= TIM_CR1_CEN;
}
